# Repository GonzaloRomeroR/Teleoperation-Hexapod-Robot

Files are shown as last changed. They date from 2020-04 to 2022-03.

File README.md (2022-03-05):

# Teleoperation-Hexapod-Robot

Design, simulation and manufacturing of and hexapod robot with 18 joints.



The full project can be found explained in spanish on *docs/hexapod_robot.pdf*

## Simulation in Unity

Hexapod simulation using Unity. In order to make it work, you need to use Unity 2020.1a15 or later. Unity 2020.1.0b5 was used in the developement.
Just download the Hexapod-Simulation-Unity folder and run the scene. 



Enable terrain Gameobject and disable floor in order to test the robot over an uneven terrain.

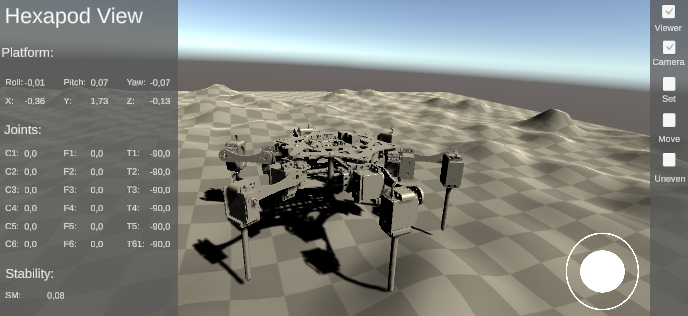
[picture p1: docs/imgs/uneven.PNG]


## Real robot movement

The robot code runs on a Raspberry Pi 3 Model B. It uses two PCA9685 to move the 18 servomotors of the robot. It is possible to use different ways to control the robot, it is possible to use a Tkinter interface to set the angular position and movement of the robot



It is also possible use a Unity simulation to control the robot via a Wifi connection, this make possible to move the robot from any computer or cellphone connected to internet.



To use a Wifi communication set the WIFI variable in the *main.py* to True. You need to set the IP address to connect in the *wifi.py*. In case the wifi variable is set to False a Tkinter interface will be displayed. 

To run the program use `python main`. This will create two processes, one for doing calculation with 18 threads and another one to write the calculated values on the PCA9685 to move the robot.

In this application we are using two types of motors TD8120 and MG996R. In case a different motor is used, you need to tweak the frequencies on the *servo_process.py* to match the ones from your motors.

All the values to describe the dimentionality of the robot to calculate the inverse kinematics of the legs and the platform are defined in *my_global.py*. Modify the lenghts according to the robot you are using.

## Hexapod models

All the models were designed using Solid Edge and can be found in the Hexapod-Model folder

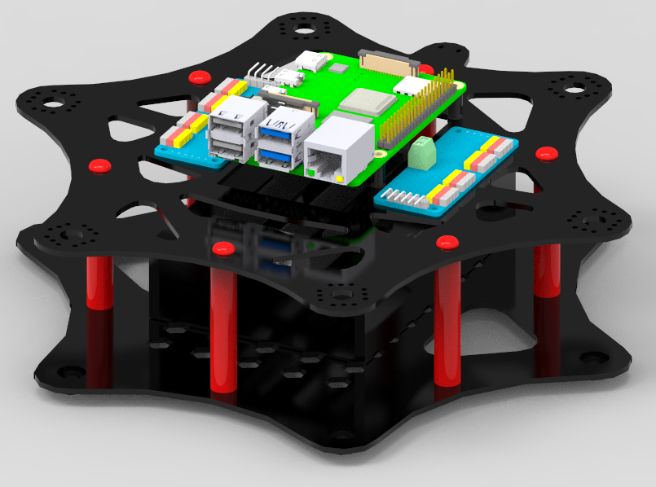
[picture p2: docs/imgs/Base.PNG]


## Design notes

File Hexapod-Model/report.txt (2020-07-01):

Nombre de informe: C:\Users\Leandro Arias\Dropbox\Robótica II\Proyecto Hexapodo\Hexapodo3D\report.txt
Hora del informe: 17/09/2018 19:32:49
Opciones de informe:
    Nombres de piezas

Conjunto de selección 1:
    Socket Head Cap Screw_AI_HX-SHCS 0.086-56x0.25x0.25-N.par:3
    Socket Head Cap Screw_AI_HX-SHCS 0.112-40x0.3125x0.3125-N.par:7
    Socket Head Cap Screw_AI_HX-SHCS 0.164-32x0.3125x0.3125-N.par:8
    Hex Nuts_21042_mil_NUT 21042 -32-N.par:2
    HMSH-01.par:1
    Socket Head Cap Screw_AI_HX-SHCS 0.086-56x0.25x0.25-N.par:7
    asb-04.par:1
    Hex Nuts_21042_mil_NUT 21042 -32-N.par:3
    Socket Head Cap Screw_AI_HX-SHCS 0.086-56x0.25x0.25-N.par:10
    Socket Head Cap Screw_AI_HX-SHCS 0.086-56x0.25x0.25-N.par:5
    Hex Nuts_21042_mil_NUT 21042 -32-N.par:4
    Socket Head Cap Screw_AI_HX-SHCS 0.164-32x0.3125x0.3125-N.par:2
    Socket Head Cap Screw_AI_HX-SHCS 0.164-32x0.3125x0.3125-N.par:6
    Socket Head Cap Screw_AI_HX-SHCS 0.112-40x0.3125x0.3125-N.par:5
    Hex Nuts_21042_mil_NUT 21042 -40-N.par:1
    Socket Head Cap Screw_AI_HX-SHCS 0.086-56x0.25x0.25-N.par:8
    Socket Head Cap Screw_AI_HX-SHCS 0.164-32x0.3125x0.3125-N.par:7
    Socket Head Cap Screw_AI_HX-SHCS 0.112-40x0.3125x0.3125-N.par:3
    Socket Head Cap Screw_AI_HX-SHCS 0.164-32x0.3125x0.3125-N.par:5
    Socket Head Cap Screw_AI_HX-SHCS 0.112-40x0.3125x0.3125-N.par:4
    HMSH-01.par:2
    asb-04.par:2
    Socket Head Cap Screw_AI_HX-SHCS 0.086-56x0.25x0.25-N.par:1
    Socket Head Cap Screw_AI_HX-SHCS 0.112-40x0.3125x0.3125-N.par:2
    Socket Head Cap Screw_AI_HX-SHCS 0.086-56x0.25x0.25-N.par:6
    Servo.par:3
    Servo.par:2
    Hex Nuts_21042_mil_NUT 21042 -32-N.par:7
    Socket Head Cap Screw_AI_HX-SHCS 0.112-40x0.3125x0.3125-N.par:6
    Hex Nuts_21042_mil_NUT 21042 -32-N.par:8
    Hex Standoff - 1.9375 x .25.par:2
    Socket Head Cap Screw_AI_HX-SHCS 0.164-32x0.3125x0.3125-N.par:1
    Socket Head Cap Screw_AM_B18.3.1M - 2.5 x 0.45 x 8 Hex SHCS -- 8NHX.par:1
    Socket Head Cap Screw_AI_HX-SHCS 0.086-56x0.25x0.25-N.par:9
    Socket Head Cap Screw_AI_HX-SHCS 0.112-40x0.3125x0.3125-N.par:1
    Socket Head Cap Screw_AI_HX-SHCS 0.086-56x0.25x0.25-N.par:12
    HMSH-01.par:3
    BB-03.par:1
    Hex Standoff - 1.9375 x .25.par:4
    Pieza3.par:1
    Hex Nuts_21042_mil_NUT 21042 -32-N.par:1
    Hex Nuts_21042_mil_NUT 21042 -32-N.par:5
    Socket Head Cap Screw_AI_HX-SHCS 0.164-32x0.3125x0.3125-N.par:4
    Socket Head Cap Screw_AI_HX-SHCS 0.112-40x0.3125x0.3125-N.par:8
    Socket Head Cap Screw_AI_HX-SHCS 0.086-56x0.25x0.25-N.par:11
    Socket Head Cap Screw_AI_HX-SHCS 0.112-40x0.3125x0.3125-N.par:9
    Socket Head Cap Screw_AI_HX-SHCS 0.086-56x0.25x0.25-N.par:4
    Hex Standoff - 1.9375 x .25.par:3
    Tibia.par:1
    Servo.par:1
    Socket Head Cap Screw_AI_HX-SHCS 0.086-56x0.25x0.25-N.par:2
    Socket Head Cap Screw_AM_B18.3.1M - 2.5 x 0.45 x 8 Hex SHCS -- 8NHX.par:2
    Socket Head Cap Screw_AI_HX-SHCS 0.164-32x0.3125x0.3125-N.par:3
    Hex Standoff - 1.9375 x .25.par:1
    Hex Nuts_21042_mil_NUT 21042 -32-N.par:6

Conjunto de selección 2:
    Pieza4.par:1

Interferencias:
    1 de 8
    Socket Head Cap Screw_AI_HX-SHCS 0.086-56x0.25x0.25-N.par:3
    Pieza4.par:1

    2 de 8
    Socket Head Cap Screw_AI_HX-SHCS 0.112-40x0.3125x0.3125-N.par:7
    Pieza4.par:1

    3 de 8
    Socket Head Cap Screw_AI_HX-SHCS 0.112-40x0.3125x0.3125-N.par:5
    Pieza4.par:1

    4 de 8
    Socket Head Cap Screw_AI_HX-SHCS 0.086-56x0.25x0.25-N.par:1
    Pieza4.par:1

    5 de 8
    Socket Head Cap Screw_AI_HX-SHCS 0.112-40x0.3125x0.3125-N.par:6
    Pieza4.par:1

    6 de 8
    Socket Head Cap Screw_AI_HX-SHCS 0.112-40x0.3125x0.3125-N.par:8
    Pieza4.par:1

    7 de 8
    Socket Head Cap Screw_AI_HX-SHCS 0.086-56x0.25x0.25-N.par:4
    Pieza4.par:1

    8 de 8
    Socket Head Cap Screw_AI_HX-SHCS 0.086-56x0.25x0.25-N.par:2
    Pieza4.par:1

    8 Interferencias Detectadas

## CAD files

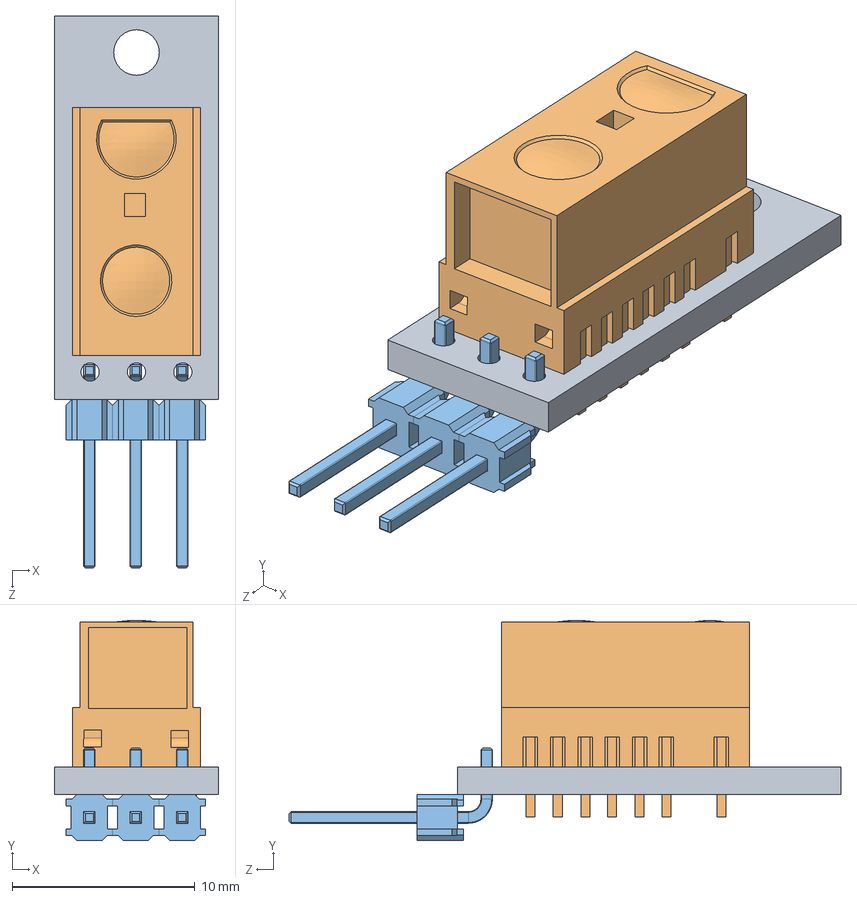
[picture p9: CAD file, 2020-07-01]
Hexapod-Model/SensorSharpDigital/SensorSharpDigital.SLDASM
9.00 x 12.1 x 30.2 mm
Base
GP2Y0D810Z0F sharp
PIN3Angulo

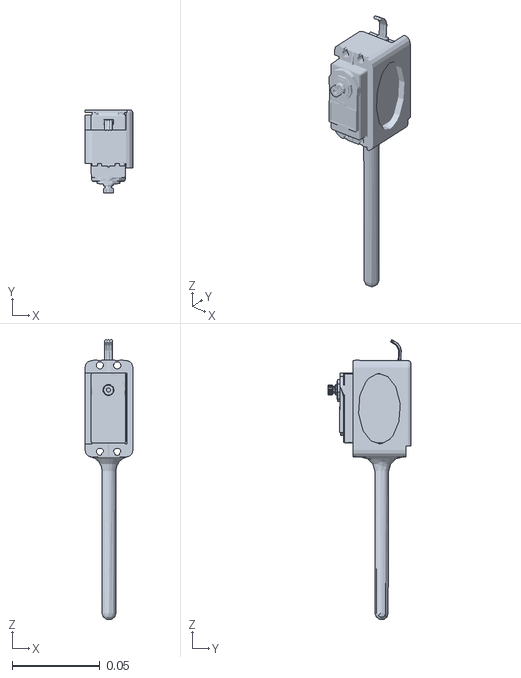
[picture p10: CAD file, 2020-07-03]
Hexapod-Simulation-Unity/Assets/RobotParts/Robot2/ensamblaje1.obj
0.0273 x 0.0474 x 0.159

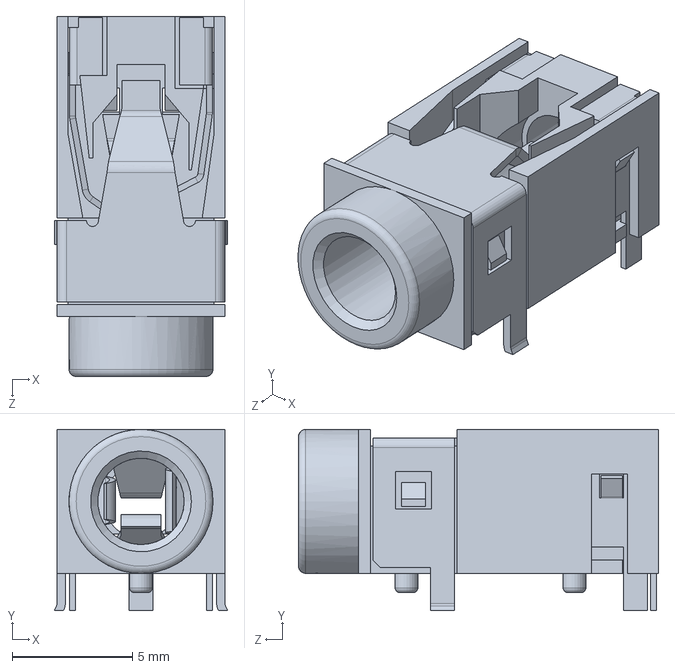
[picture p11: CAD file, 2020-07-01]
Hexapod-Model/raspberry-pi-4-model-b-1.snapshot.3/Microphone Plug, RPi4ModelB.SLDPRT
7.23 x 7.55 x 15.0 mm

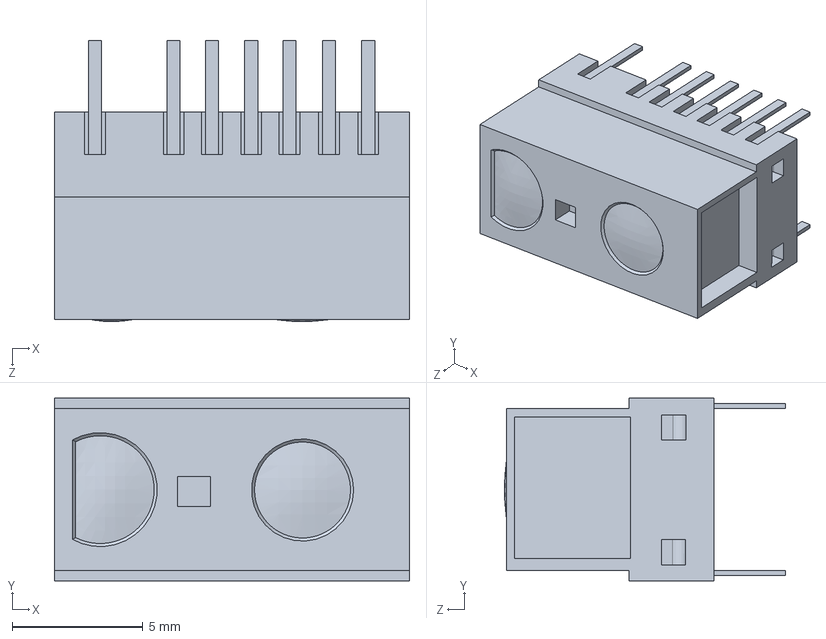
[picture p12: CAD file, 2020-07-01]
Hexapod-Model/SensorSharpDigital/GP2Y0D810Z0F sharp.SLDPRT
13.6 x 7.00 x 10.8 mm

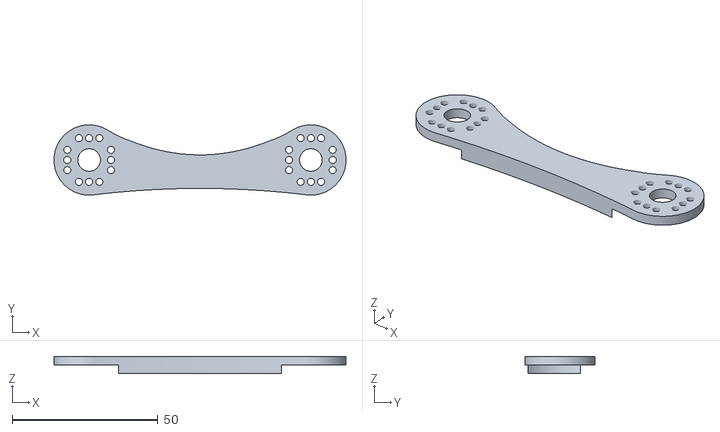
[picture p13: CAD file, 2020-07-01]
Hexapod-Model/TibiaCompensacion.stl
100.3 x 24.1 x 6.00

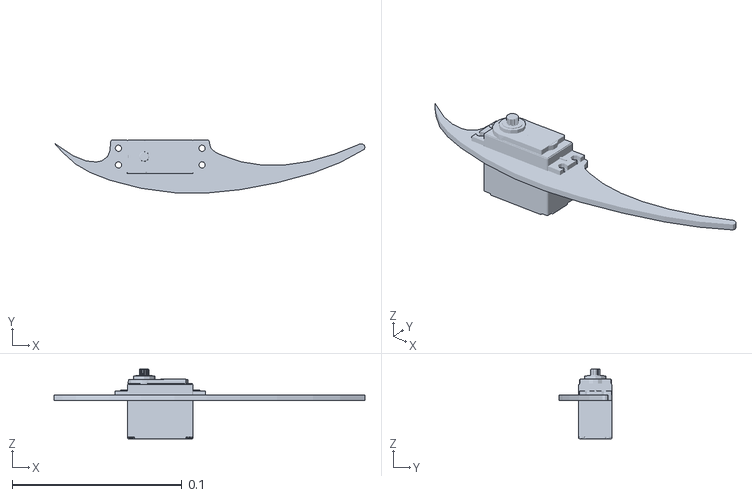
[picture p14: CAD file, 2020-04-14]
Hexapod-Simulation-Unity/Assets/RobotParts/Robot1/Tibia.obj
0.183 x 0.0313 x 0.041

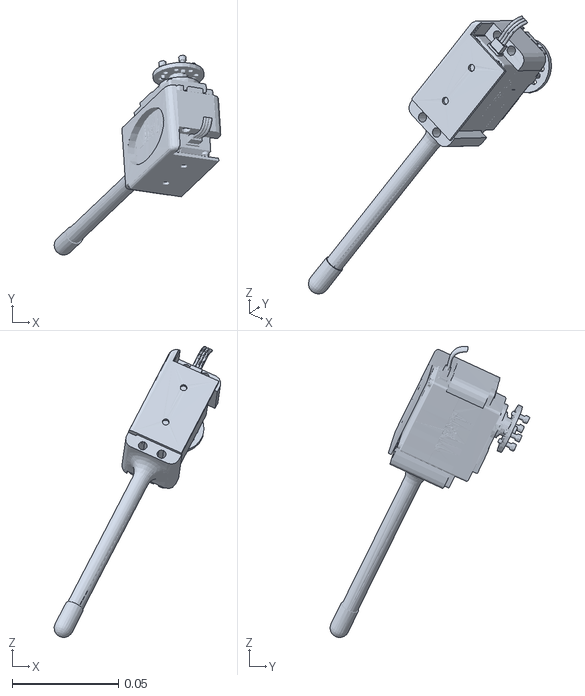
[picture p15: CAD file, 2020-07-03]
Hexapod-Simulation-Unity/Assets/RobotParts/Robot2/TIBIA.obj
0.0783 x 0.0939 x 0.137

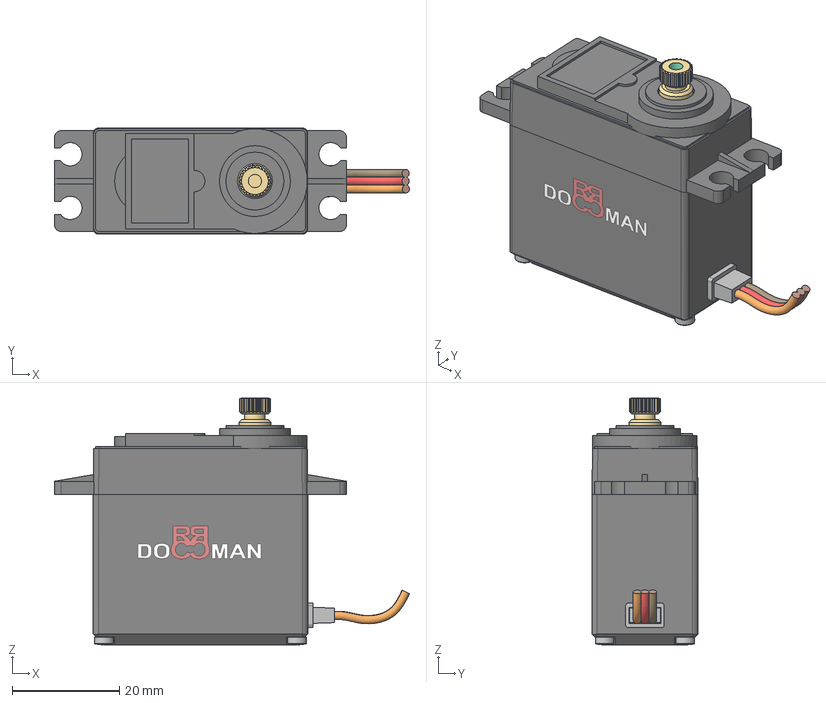
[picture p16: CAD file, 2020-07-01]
Hexapod-Model/DoMan DM-S2000MD.stp
66.2 x 19.8 x 46.0 mm
DM-S200MD Body
DM-S200MD Top Cap
Top Gear
Screw x 4

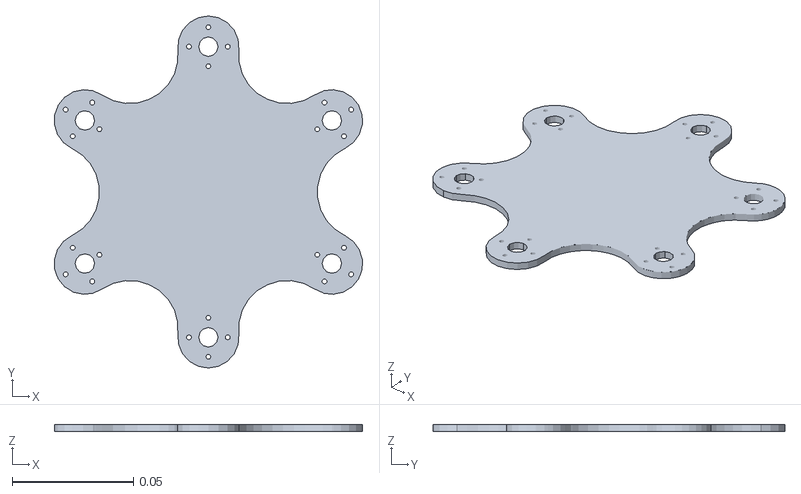
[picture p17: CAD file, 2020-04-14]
Hexapod-Simulation-Unity/Assets/RobotParts/Robot1/Base.obj
0.127 x 0.145 x 0.003

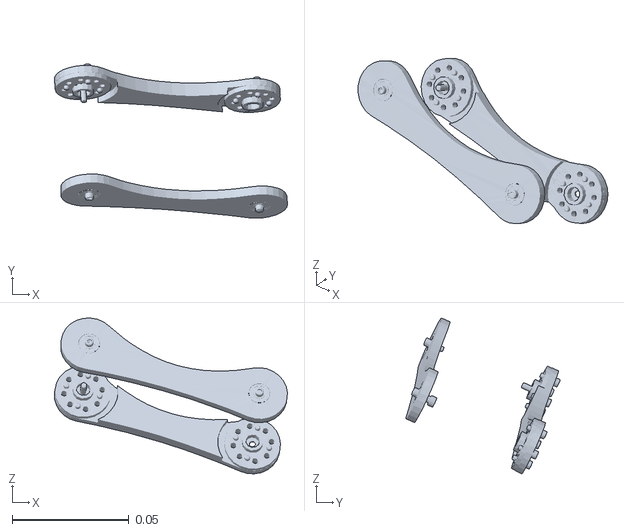
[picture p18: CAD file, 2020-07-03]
Hexapod-Simulation-Unity/Assets/RobotParts/Robot2/FEMUR.obj
0.0999 x 0.0662 x 0.0668

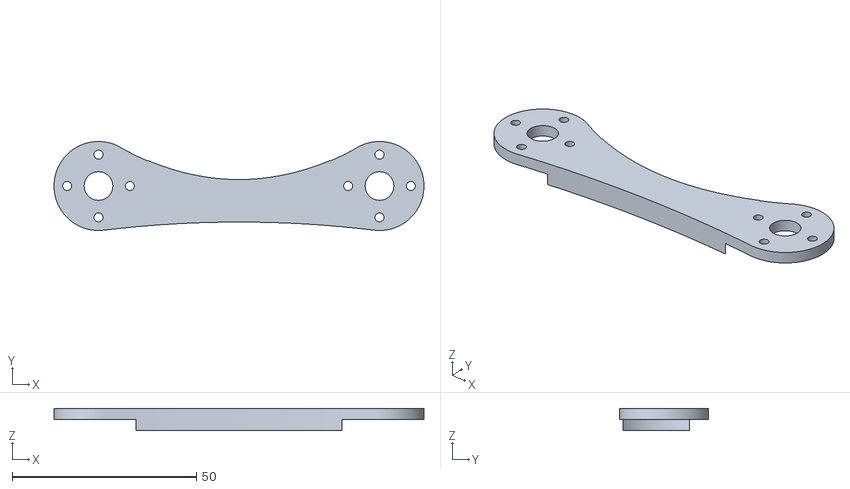
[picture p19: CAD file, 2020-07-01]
Hexapod-Model/coxa.stl
100.3 x 24.1 x 6.00

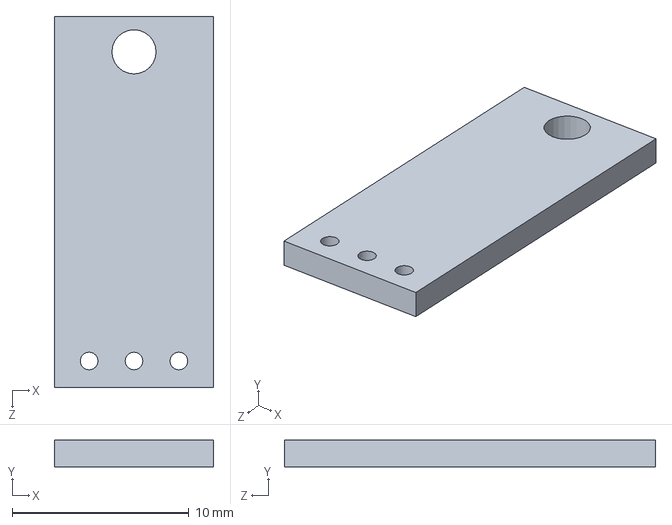
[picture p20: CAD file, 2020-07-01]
Hexapod-Model/SensorSharpDigital/Base.SLDPRT
9.00 x 1.50 x 21.0 mm

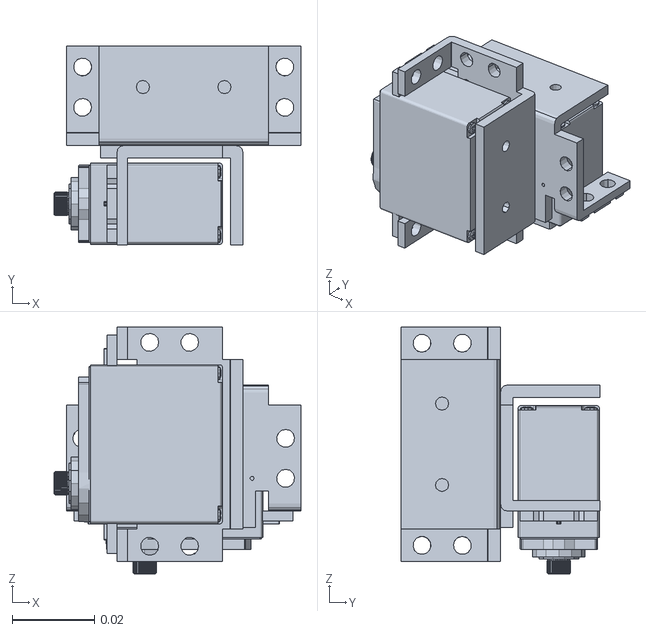
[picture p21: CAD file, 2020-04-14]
Hexapod-Simulation-Unity/Assets/RobotParts/Robot1/Coxa.obj
0.06 x 0.0484 x 0.06

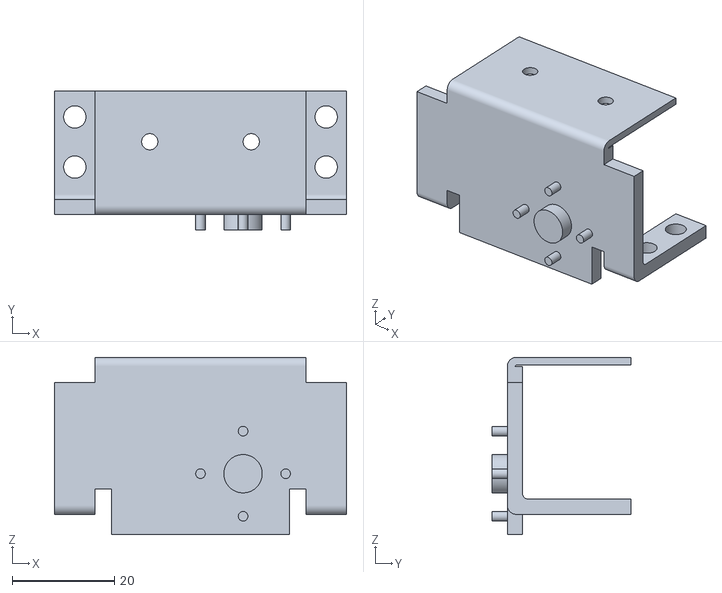
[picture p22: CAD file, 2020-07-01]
Hexapod-Model/coixa2.stl
57.2 x 27.2 x 34.7

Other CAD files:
Hexapod-Model/raspberry-pi-4-model-b-1.snapshot.3/VIA VL805 PCIe USB 3.0 controller, RPi4ModelB.SLDPRT
Hexapod-Model/DoMan DM-S2000MD.x_t
Hexapod-Model/SensorSharpDigital/PIN3Angulo.SLDPRT
Hexapod-Model/coixa1.stl
Hexapod-Model/raspberry-pi-4-model-b-1.snapshot.3/2.54 mm DUPONT MALE PIN HEADER, IO, 2X40, RPi4ModelB.SLDPRT
Hexapod-Model/raspberry-pi-4-model-b-1.snapshot.3/2.54 mm DUPONT MALE PIN HEADER, POE, 2X2, RPi4ModelB.SLDPRT
Hexapod-Model/raspberry-pi-4-model-b-1.snapshot.3/2X USB2.0 PORTS, RPi4ModelB.SLDPRT
Hexapod-Model/raspberry-pi-4-model-b-1.snapshot.3/2X USB3.0 PORTS, RPi4ModelB.SLDPRT
Hexapod-Model/raspberry-pi-4-model-b-1.snapshot.3/Broadcom BCM2711B0 CPU, RPi4ModelB.SLDPRT
Hexapod-Model/raspberry-pi-4-model-b-1.snapshot.3/Broadcom BCM54213PE Gigabit Ethernet Transceiver, RPi4ModelB.SLDPRT
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

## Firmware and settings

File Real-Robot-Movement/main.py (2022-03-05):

import multiprocessing
import time
from multiprocessing import Manager, Process
from multiprocessing.managers import BaseManager
from threading import Event, Thread, Timer

import numpy as np

import GUI
import joint_timer as tm
import planner_timer as ptm
from my_global import Global
from servo_process import servo_run
from wifi import WifiClient

TIMER_TIME = 0.01
PLANNER_TIME = 0.2
ARTICULATION_NUMBER = 18
WIFI = True

start_time = time.time()


def main():
    manager = Manager()
    commands = manager.list()
    for i in range(18):
        commands.append(0)

    commands[2] = -90
    commands[5] = -90
    commands[8] = -90
    commands[11] = -90
    commands[14] = -90
    commands[17] = -90

    gl = Global(commands)

    # Start timer
    stop_flag = Event()
    for i in range(18):
        gl.timers.append(tm.MyTimer(stop_flag, TIMER_TIME, gl, i))
        gl.timers[i].start()

    plan_timer = ptm.PlannerTimer(stop_flag, PLANNER_TIME, gl)
    plan_timer.start()

    p = Process(target=servo_run, args=(commands,))
    p.start()

    if WIFI == True:
        WifiClient(gl)
    else:
        GUI.runGUI(gl)
    p.join()


if __name__ == "__main__":
    main()

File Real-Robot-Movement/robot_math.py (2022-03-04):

import math

import numpy as np


class RobotMath:
    """
    Class that provides the methods to calculate the kinematics of the robot.
    Inverse kinematics of the robot and platform are provided.

    """

    def leg_inverse_kinematics(self, x, y, z, l1, l2, l3):
        theta1 = math.atan2(y, x)
        x0 = x - l1 * math.cos(theta1)
        y0 = y - l1 * math.sin(theta1)
        p2 = x0 ** 2 + y0 ** 2 + z ** 2

        theta2 = math.acos(
            (-(l3 ** 2) + l2 ** 2 + p2) / (2 * l2 * p2 ** 0.5)
        ) + math.atan2(z, (x0 ** 2 + y0 ** 2) ** 0.5)

        theta3 = -math.acos((p2 - l2 ** 2 - l3 ** 2) / (2 * l2 * l3))

        theta1 = theta1 * 180.0 / math.pi
        theta2 = theta2 * 180.0 / math.pi
        theta3 = theta3 * 180.0 / math.pi
        return [theta1, theta2, theta3]

    def platform_inverse_kinematics(
        self, x, y, z, roll, pitch, yaw, radius, angle, l1, l2, l3, initialX, initialZ
    ):

        roll = roll * math.pi / 180.0
        pitch = pitch * math.pi / 180.0
        yaw = yaw * math.pi / 180.0
        angles = [[0, 0, 0] for i in range(6)]
        O = np.transpose(np.array([x, y, z]))
        R = np.array(
            [
                [
                    math.cos(yaw) * math.cos(pitch),
                    math.cos(yaw) * math.sin(pitch) * math.sin(roll)
                    - math.sin(yaw) * math.cos(roll),
                    math.cos(yaw) * math.sin(pitch) * math.cos(roll)
                    + math.sin(yaw) * math.sin(roll),
                ],
                [
                    math.sin(yaw) * math.cos(pitch),
                    math.sin(yaw) * math.sin(pitch) * math.sin(roll)
                    + math.cos(yaw) * math.cos(roll),
                    math.sin(yaw) * math.sin(pitch) * math.cos(roll)
                    - math.cos(yaw) * math.sin(roll),
                ],
                [
                    -math.sin(pitch),
                    math.cos(pitch) * math.sin(roll),
                    math.cos(pitch) * math.cos(roll),
                ],
            ]
        )

        S1 = np.array(
            [
                [radius * math.cos(angle), radius * math.sin(angle), 0],
                [
                    radius * math.cos(angle + math.pi / 3),
                    radius * math.sin(angle + math.pi / 3),
                    0,
                ],
                [
                    radius * math.cos(angle + 2 * math.pi / 3),
                    radius * math.sin(angle + 2 * math.pi / 3),
                    0,
                ],
                [
                    radius * math.cos(angle + math.pi),
                    radius * math.sin(angle + math.pi),
                    0,
                ],
                [
                    radius * math.cos(angle + 4 * math.pi / 3),
                    radius * math.sin(angle + 4 * math.pi / 3),
                    0,
                ],
                [
                    radius * math.cos(angle + 5 * math.pi / 3),
                    radius * math.sin(angle + 5 * math.pi / 3),
                    0,
                ],
            ]
        )

        S1 = np.transpose(S1)
        U = np.array(
            [
                [
                    (initialX + radius) * math.cos(angle),
                    (initialX + radius) * math.sin(angle),
                    initialZ,
                ],
                [
                    (initialX + radius) * math.cos(angle + math.pi / 3),
                    (initialX + radius) * math.sin(angle + math.pi / 3),
                    initialZ,
                ],
                [
                    (initialX + radius) * math.cos(angle + 2 * math.pi / 3),
                    (initialX + radius) * math.sin(angle + 2 * math.pi / 3),
                    initialZ,
                ],
                [
                    (initialX + radius) * math.cos(angle + math.pi),
                    (initialX + radius) * math.sin(angle + math.pi),
                    initialZ,
                ],
                [
                    (initialX + radius) * math.cos(angle + 4 * math.pi / 3),
                    (initialX + radius) * math.sin(angle + 4 * math.pi / 3),
                    initialZ,
                ],
                [
                    (initialX + radius) * math.cos(angle + 5 * math.pi / 3),
                    (initialX + radius) * math.sin(angle + 5 * math.pi / 3),
                    initialZ,
                ],
            ]
        )
        U = np.transpose(U)
        L = np.zeros((3, 6))
        alpha = np.zeros((1, 6))
        beta = np.zeros((1, 6))
        gamma = np.zeros((1, 6))
        S2 = np.zeros((3, 6))
        LPV = np.zeros((3, 6))
        LP = np.zeros((1, 6))

        for i in range(6):
            L[:, i] = np.add(np.add(O, R.dot(S1[:, i])), -U[:, i])
            alpha[0, i] = math.atan2(L[1, i], L[0, i])

            S2[0, i] = S1[0, i] - l1 * math.cos(alpha[0, i])
            S2[1, i] = S1[1, i] - l1 * math.sin(alpha[0, i])
            S2[2, i] = S1[2, i]

            LPV[:, i] = np.add(np.add(O, R.dot(S2[:, i])), -U[:, i])
            LP[0, i] = np.linalg.norm(LPV[:, i])

            p = math.atan2(LPV[2, i], (LPV[1, i] ** 2 + LPV[0, i] ** 2) ** 0.5)
            phi = math.asin((LPV[2, i] - L[2, i]) / l1)
            beta[0, i] = math.acos(
                (l2 ** 2 - l3 ** 2 + LP[0, i] ** 2) / (2 * l2 * LP[0, i])
            ) - (p + phi)
            gamma[0, i] = (
                math.pi
                - math.acos((l2 ** 2 + l3 ** 2 - LP[0, i] ** 2) / (2 * l2 * l3)) * -1.0
            )

        increment = 0.0
        for i in range(6):
            alpha[0, i] = alpha[0, i] + increment
            increment = increment - math.pi / 3.0
        for i in range(6):
            angles[i][0] = alpha[0, i] * 180.0 / math.pi
            if angles[i][0] > 90:
                angles[i][0] = angles[i][0] - 180
            if angles[i][0] < -90:
                angles[i][0] = angles[i][0] + 180
            angles[i][1] = beta[0, i] * 180.0 / math.pi
            angles[i][2] = gamma[0, i] * 180.0 / math.pi - 360

        return angles

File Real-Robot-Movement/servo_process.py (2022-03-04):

import time
from threading import Event, Thread, Timer

import GUI

DEBUG = False
TIMER = 0.01

MAX_FREQUENCY = 2250
MIN_FREQUENCY = 450

# TD8120
MAX_FREQUENCY = 2500
MIN_FREQUENCY = 500

# MG996R
MAX_FREQUENCY = 2550
MIN_FREQUENCY = 450


def servo_run(commands):
    """
    Function that write the joint commands in the I2C bus in order to move the robot
    Args:
        commands ([list]): [Shared list between processes that stores the 18 joint commands]
    """
    if DEBUG == False:
        from adafruit_servokit import ServoKit

        kit = ServoKit(channels=16)
        kit2 = ServoKit(channels=16, address=0x41)

    offsets = [
        [138, 80, 30],
        [138, 69, 30],
        [100, 69, 38],
        [127, 72, 40],
        [142, 75, 35],
        [98, 71, 40],
    ]

    min_coxa = -25
    max_coxa = 25

    min_femur = -90
    max_femur = 90

    min_tibia = -160
    max_tibia = 0

    if DEBUG == False:
        for i in range(16):
            kit.servo[i].set_pulse_width_range(MIN_FREQUENCY, MAX_FREQUENCY)
            kit2.servo[i].set_pulse_width_range(MIN_FREQUENCY, MAX_FREQUENCY)

    while 1:
        if DEBUG == True:
            # walking_input(0.0)
            print(commands)
            time.sleep(TIMER)

        else:
            # walking_input(0.0)
            print(commands)
            try:
                if commands[0] >= min_coxa and commands[0] <= max_coxa:
                    kit2.servo[0].angle = commands[0] + offsets[0][0]
                if commands[1] >= min_femur and commands[1] <= max_femur:
                    kit2.servo[1].angle = commands[1] + offsets[0][1]
                if commands[2] >= min_tibia and commands[2] <= max_tibia:
                    kit2.servo[2].angle = -commands[2] + offsets[0][2]

                if commands[3] >= min_coxa and commands[3] <= max_coxa:
                    kit2.servo[3].angle = commands[3] + offsets[1][0]
                if commands[4] >= min_femur and commands[4] <= max_femur:
                    kit2.servo[4].angle = commands[4] + offsets[1][1]
                if commands[5] >= min_tibia and commands[5] <= max_tibia:
                    kit2.servo[5].angle = -commands[5] + offsets[1][2]

                if commands[6] >= min_coxa and commands[6] <= max_coxa:
                    kit.servo[6].angle = commands[6] + offsets[2][0]
                if commands[7] >= min_femur and commands[7] <= max_femur:
                    kit.servo[7].angle = commands[7] + offsets[2][1]
                if commands[8] >= min_tibia and commands[8] <= max_tibia:
                    kit.servo[8].angle = -commands[8] + offsets[2][2]

                if commands[9] >= min_coxa and commands[9] <= max_coxa:
                    kit.servo[3].angle = commands[9] + offsets[3][0]
                if commands[10] >= min_femur and commands[10] <= max_femur:
                    kit.servo[4].angle = commands[10] + offsets[3][1]
                if commands[11] >= min_tibia and commands[11] <= max_tibia:
                    kit.servo[5].angle = -commands[11] + offsets[3][2]

                if commands[12] >= min_coxa and commands[12] <= max_coxa:
                    kit.servo[2].angle = commands[12] + offsets[4][0]
                if commands[13] >= min_femur and commands[13] <= max_femur:
                    kit.servo[1].angle = commands[13] + offsets[4][1]
                if commands[14] >= min_tibia and commands[14] <= max_tibia:
                    kit.servo[0].angle = -commands[14] + offsets[4][2]

                if commands[15] >= min_coxa and commands[15] <= max_coxa:
                    kit2.servo[6].angle = commands[15] + offsets[5][0]
                if commands[16] >= min_femur and commands[16] <= max_femur:
                    kit2.servo[7].angle = commands[16] + offsets[5][1]
                if commands[17] >= min_tibia and commands[17] <= max_tibia:
                    kit2.servo[8].angle = -commands[17] + offsets[5][2]
            except:
                print("I2C error")

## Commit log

2020-04-14 Dynamical robot finished, starting to add uneven terrain
    [Base.obj, Coxa.obj, Femur.obj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]
2020-04-17 Add to github
    [Base.obj, Coxa.obj, Femur.obj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]
2020-06-17 Inverse kinematics added, robot calibration
2020-06-20 Use two pca to move the motors
2020-06-26 Added comunication between Unity and Raspberry, documentation and other minor errors
    [GUI.py, main.py, my_global.py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]
2020-07-01 Solid Edge model uploaded
    [2.54 mm DUPONT MALE PIN HEADER, IO, 2X20, RPi4ModelB.SLDPRT, 2.54 mm DUPONT MALE PIN HEADER, IO, 2X40, RPi4ModelB.SLDPRT, 2.54 mm DUPONT MALE PIN HEADER, POE, 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]
2020-07-03 Unity new robot added to simulation
    [Base.obj, Coxa.obj, FEMUR.obj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]
